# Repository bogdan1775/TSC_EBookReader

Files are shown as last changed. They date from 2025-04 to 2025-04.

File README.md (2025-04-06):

### Croitoru Constantin-Bogdan 334CA
# Proiect TSC

## Diagrama Bloc
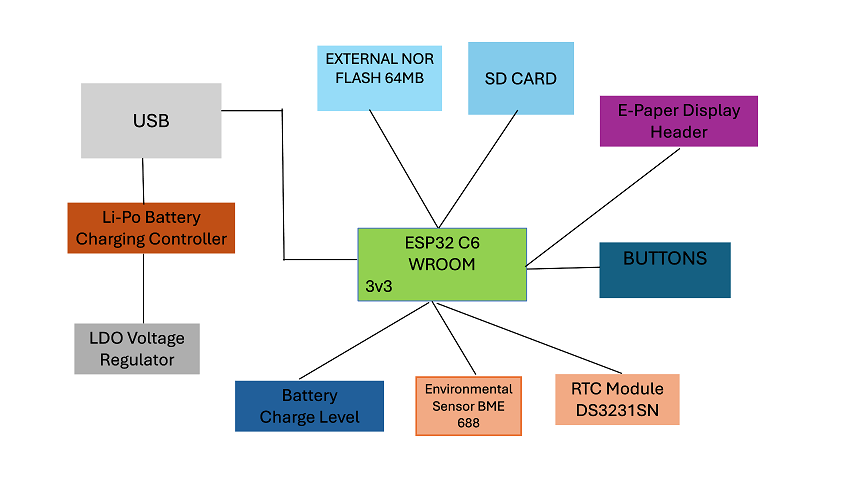
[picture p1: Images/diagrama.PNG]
Diagrama


## Bill Of Materials
| Nume | Link componenta | Link Datasheet |
|---|---|---|
|	BOOT_BUTTON	|	https://www.snapeda.com/parts/EVQP7L01P/Panasonic/view-part/?welcome=home&ref=search&t=evqp7l01p	|	https://industry.panasonic.com/global/en/downloads?tab=catalog&small_g_cd=203&part_no=EVQPUJ02K	|
|	C1	|	https://componentsearchengine.com/part-view/CC0402MRX5R5BB106/YAGEO	|	https://componentsearchengine.com/Datasheets/2/CC0402MRX5R5BB106.pdf	|
|	C1_BAT	|	https://componentsearchengine.com/part-view/CC0402MRX5R5BB106/YAGEO	|	https://componentsearchengine.com/Datasheets/2/CC0402MRX5R5BB106.pdf	|
|	C1_BAT1	|	https://www.snapeda.com/parts/CC0402DRNPO9BN5R1/Yageo/view-part/?ref=dk&t=LTSPICE_CC0402&con_ref=None	|	https://s3.amazonaws.com/snapeda/datasheet/CC0402DRNPO9BN5R1_Yageo.pdf	|
|	C2_BAT1	|	https://www.snapeda.com/parts/CC0402DRNPO9BN5R1/Yageo/view-part/?ref=dk&t=LTSPICE_CC0402&con_ref=None	|	https://s3.amazonaws.com/snapeda/datasheet/CC0402DRNPO9BN5R1_Yageo.pdf	|
|	C1_BAT2	| https://www.snapeda.com/parts/CC0402DRNPO9BN5R1/Yageo/view-part/?ref=dk&t=LTSPICE_CC0402&con_ref=None	|	https://s3.amazonaws.com/snapeda/datasheet/CC0402DRNPO9BN5R1_Yageo.pdf	|
|	C2	|	https://componentsearchengine.com/part-view/CC0402MRX5R5BB106/YAGEO	|	https://componentsearchengine.com/Datasheets/2/CC0402MRX5R5BB106.pdf	|
|	C2_BAT	|	https://componentsearchengine.com/part-view/CC0402MRX5R5BB106/YAGEO	|	https://componentsearchengine.com/Datasheets/2/CC0402MRX5R5BB106.pdf	|
|	C3	|	https://componentsearchengine.com/part-view/T491B107M006AT/KEMET	|	https://s3.amazonaws.com/snapeda/datasheet/TAJB475K025RNJ_AVX.pdf	|
|	C4	|	https://componentsearchengine.com/part-view/CC0402MRX5R5BB106/YAGEO	|	https://componentsearchengine.com/Datasheets/2/CC0402MRX5R5BB106.pdf	|
|	C4_USB	|	https://componentsearchengine.com/part-view/CC0402MRX5R5BB106/YAGEO	|	https://componentsearchengine.com/Datasheets/2/CC0402MRX5R5BB106.pdf	|
|	C5	|	https://componentsearchengine.com/part-view/CC0402MRX5R5BB106/YAGEO	|	https://componentsearchengine.com/Datasheets/2/CC0402MRX5R5BB106.pdf	|
|	C5_USB	|	https://componentsearchengine.com/part-view/CC0402MRX5R5BB106/YAGEO	|	https://componentsearchengine.com/Datasheets/2/CC0402MRX5R5BB106.pdf	|
|	C6	|	https://componentsearchengine.com/part-view/CC0402MRX5R5BB106/YAGEO	|	https://componentsearchengine.com/Datasheets/2/CC0402MRX5R5BB106.pdf	|
|	C7	|	https://componentsearchengine.com/part-view/CC0402MRX5R5BB106/YAGEO	|	https://componentsearchengine.com/Datasheets/2/CC0402MRX5R5BB106.pdf	|
|	C8	|	https://componentsearchengine.com/part-view/CC0402MRX5R5BB106/YAGEO	|	https://componentsearchengine.com/Datasheets/2/CC0402MRX5R5BB106.pdf	|
|	C9	|	https://www.snapeda.com/parts/CC0402DRNPO9BN5R1/Yageo/view-part/?ref=dk&t=LTSPICE_CC0402&con_ref=None	|	https://s3.amazonaws.com/snapeda/datasheet/CC0402DRNPO9BN5R1_Yageo.pdf	|
|	C10	|	https://componentsearchengine.com/part-view/CC0402MRX5R5BB106/YAGEO	|	https://componentsearchengine.com/Datasheets/2/CC0402MRX5R5BB106.pdf	|
|	C10_SUPERCAP	|	https://www.snapeda.com/parts/CPH3225A/Seiko+Instruments/view-part/?ref=eda	|	https://www.snapeda.com/parts/CPH3225A/Seiko%20Instruments/datasheet/	|
|	CHANGE_BUTTON	|	https://www.snapeda.com/parts/EVQP7L01P/Panasonic/view-part/?welcome=home&ref=search&t=evqp7l01p	|	https://industry.panasonic.com/global/en/downloads?tab=catalog&small_g_cd=203&part_no=EVQPUJ02K	|
|	CHG_LED	|	https://www.snapeda.com/parts/KP-1608SURCK/Kingbright/view-part/?ref=search&t=LED%200603	|	https://www.snapeda.com/parts/KP-1608SURCK/Kingbright/datasheet/	|
|	C_DELAY	|	https://componentsearchengine.com/part-view/CC0402MRX5R5BB106/YAGEO	|	https://componentsearchengine.com/Datasheets/2/CC0402MRX5R5BB106.pdf	|
|	D1	|	https://www.snapeda.com/parts/USBLC6-2SC6Y/STMicroelectronics/view-part/?ref=snap	|	https://www.snapeda.com/parts/USBLC6-2SC6Y/STMicroelectronics/datasheet/	|
|	D2	|	https://ro.mouser.com/ProductDetail/KYOCERA-AVX/SD0805S020S1R0?qs=jCA%252BPfw4LHbpkAoSnwrdjw%3D%3D	|	http://datasheets.avx.com/schottky.pdf	|
|	D3	|	https://www.snapeda.com/parts/MBR0530/Onsemi/view-part/?ref=eda	|	https://www.snapeda.com/parts/MBR0530/ON%20Semiconductor/datasheet/	|
|	D4	|	https://www.snapeda.com/parts/MBR0530/Onsemi/view-part/?ref=eda	|	https://www.snapeda.com/parts/MBR0530/ON%20Semiconductor/datasheet/	|
|	D5	|	https://www.snapeda.com/parts/MBR0530/Onsemi/view-part/?ref=eda	|	https://www.snapeda.com/parts/MBR0530/ON%20Semiconductor/datasheet/	|
|	D6	|	https://www.snapeda.com/parts/PGB1010603MR/Littelfuse/view-part/?ref=eda	|	https://www.snapeda.com/parts/PGB1010603MR/Littelfuse%20Inc./datasheet/	|
|	D7	|	https://ro.mouser.com/ProductDetail/KYOCERA-AVX/SD0805S020S1R0?qs=jCA%252BPfw4LHbpkAoSnwrdjw%3D%3D	|	http://datasheets.avx.com/schottky.pdf	|
|	D8	|	https://www.snapeda.com/parts/PGB1010603MR/Littelfuse/view-part/?ref=eda	|	https://www.snapeda.com/parts/PGB1010603MR/Littelfuse%20Inc./datasheet/	|
|	D9	|	https://www.snapeda.com/parts/PGB1010603MR/Littelfuse/view-part/?ref=eda	|	https://www.snapeda.com/parts/PGB1010603MR/Littelfuse%20Inc./datasheet/	|
|	D10	|	https://www.snapeda.com/parts/PGB1010603MR/Littelfuse/view-part/?ref=eda	|	https://www.snapeda.com/parts/PGB1010603MR/Littelfuse%20Inc./datasheet/	|
|	D11	|	https://www.snapeda.com/parts/PGB1010603MR/Littelfuse/view-part/?ref=eda	|	https://www.snapeda.com/parts/PGB1010603MR/Littelfuse%20Inc./datasheet/	|
|	D12	|	https://www.snapeda.com/parts/PGB1010603MR/Littelfuse/view-part/?ref=eda	|	https://www.snapeda.com/parts/PGB1010603MR/Littelfuse%20Inc./datasheet/	|
|	EPD_C1	|	https://componentsearchengine.com/part-view/CC0402MRX5R5BB106/YAGEO	|	https://componentsearchengine.com/Datasheets/2/CC0402MRX5R5BB106.pdf	|
|	EPD_C2	|	https://componentsearchengine.com/part-view/CC0402MRX5R5BB106/YAGEO	|	https://componentsearchengine.com/Datasheets/2/CC0402MRX5R5BB106.pdf	|
|	EPD_C5	|	https://componentsearchengine.com/part-view/CC0402MRX5R5BB106/YAGEO	|	https://componentsearchengine.com/Datasheets/2/CC0402MRX5R5BB106.pdf	|
|	EPD_C6	|	https://componentsearchengine.com/part-view/CC0402MRX5R5BB106/YAGEO	|	https://componentsearchengine.com/Datasheets/2/CC0402MRX5R5BB106.pdf	|
|	EPD_C7	|	https://componentsearchengine.com/part-view/CC0402MRX5R5BB106/YAGEO	|	https://componentsearchengine.com/Datasheets/2/CC0402MRX5R5BB106.pdf	|
|	EPD_C8	|	https://componentsearchengine.com/part-view/CC0402MRX5R5BB106/YAGEO	|	https://componentsearchengine.com/Datasheets/2/CC0402MRX5R5BB106.pdf	|
|	EPD_C9	|	https://componentsearchengine.com/part-view/CC0402MRX5R5BB106/YAGEO	|	https://componentsearchengine.com/Datasheets/2/CC0402MRX5R5BB106.pdf	|
|	EPD_C10	|	https://componentsearchengine.com/part-view/CC0402MRX5R5BB106/YAGEO	|	https://componentsearchengine.com/Datasheets/2/CC0402MRX5R5BB106.pdf	|
|	EPD_C11	|	https://componentsearchengine.com/part-view/CC0402MRX5R5BB106/YAGEO	|	https://componentsearchengine.com/Datasheets/2/CC0402MRX5R5BB106.pdf	|
|	EPD_C12	|	https://componentsearchengine.com/part-view/CC0402MRX5R5BB106/YAGEO	|	https://componentsearchengine.com/Datasheets/2/CC0402MRX5R5BB106.pdf	|
|	IC1	|	https://componentsearchengine.com/part-view/BD5229G-TR/ROHM%20Semiconductor	|	https://datasheet.datasheetarchive.com/originals/distributors/Datasheets_SAMA/f2b9741ef86007909f138d561a359946.pdf	|
|	IC4	|	https://componentsearchengine.com/part-view/XC6220A331MR-G/Torex	|	https://product.torexsemi.com/system/files/series/xc6220.pdf	|
|	J1	|	https://componentsearchengine.com/part-view/FH34SRJ-24S-0.5SH(99)/Hirose	|	https://www.hirose.com/en/product/document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	|
|	J2	|	https://componentsearchengine.com/part-view/USB4110-GF-A/GCT%20(GLOBAL%20CONNECTOR%20TECHNOLOGY)	|	https://gct.co/files/drawings/usb4110.pdf	|
|	J3	|	https://componentsearchengine.com/part-view/SM04B-SRSS-TB(LF)(SN)/JST%20(JAPAN%20SOLDERLESS%20TERMINALS)	| - |
|	J4	|	https://store.comet.srl.ro/Catalogue/Product/43497/	|	https://store.comet.srl.ro/Catalogue/Product/43497/	|
|	L1	|	https://ro.mouser.com/ProductDetail/Wurth-Elektronik/744043680?qs=PGXP4M47uW6VkZq%252BkzjrHA%3D%3D	|	https://www.we-online.com/components/products/datasheet/744043680.pdf	|
|	PFMF.050.1	|	https://ro.mouser.com/ProductDetail/EPCOS-TDK/B72520T0350K062?qs=dEfas%2FXlABIszF52uu7vrg%3D%3D	|	https://www.mouser.co.uk/ProductDetail/EPCOS-TDK/B72520T0350K062?qs=dEfas%2FXlABIszF52uu7vrg%3D%3D	|
|	Q1	|	https://componentsearchengine.com/part-view/DMG2305UX-7/Diodes%20Incorporated	|	https://www.diodes.com//assets/Datasheets/DMG2305UX.pdf	|
|	Q2	|	https://componentsearchengine.com/part-view/DMG2305UX-7/Diodes%20Incorporated	|	https://www.diodes.com//assets/Datasheets/DMG2305UX.pdf	|
|	Q3	|	https://componentsearchengine.com/part-view/SI1308EDL-T1-GE3/Vishay	|	https://componentsearchengine.com/Datasheets/1/SI1308EDL-T1-GE3.pdf	|
|	R1	|	https://componentsearchengine.com/part-view/R0402%201%25%20100%20K%20(RC0402FR-07100KL)/YAGEO	|	https://www.yageo.com/upload/media/product/products/datasheet/rchip/PYu-RC_Group_51_RoHS_L_12.pdf	|
|	R1-PINH	|	https://componentsearchengine.com/part-view/R0402%201%25%20100%20K%20(RC0402FR-07100KL)/YAGEO	|	https://www.yageo.com/upload/media/product/products/datasheet/rchip/PYu-RC_Group_51_RoHS_L_12.pdf	|
|	R1-PINH1	|	https://componentsearchengine.com/part-view/R0402%201%25%20100%20K%20(RC0402FR-07100KL)/YAGEO	|	https://www.yageo.com/upload/media/product/products/datasheet/rchip/PYu-RC_Group_51_RoHS_L_12.pdf	|
|	R1_BAT	|	https://componentsearchengine.com/part-view/R0402%201%25%20100%20K%20(RC0402FR-07100KL)/YAGEO	|	https://www.yageo.com/upload/media/product/products/datasheet/rchip/PYu-RC_Group_51_RoHS_L_12.pdf	|
|	R1_PWRUSB	|	https://componentsearchengine.com/part-view/R0402%201%25%20100%20K%20(RC0402FR-07100KL)/YAGEO	|	https://www.yageo.com/upload/media/product/products/datasheet/rchip/PYu-RC_Group_51_RoHS_L_12.pdf	|
|	R2	|	https://componentsearchengine.com/part-view/R0402%201%25%20100%20K%20(RC0402FR-07100KL)/YAGEO	|	https://www.yageo.com/upload/media/product/products/datasheet/rchip/PYu-RC_Group_51_RoHS_L_12.pdf	|
|	R2-PINH	|	https://componentsearchengine.com/part-view/R0402%201%25%20100%20K%20(RC0402FR-07100KL)/YAGEO	|	https://www.yageo.com/upload/media/product/products/datasheet/rchip/PYu-RC_Group_51_RoHS_L_12.pdf	|
|	R2-PINH1	|	https://componentsearchengine.com/part-view/R0402%201%25%20100%20K%20(RC0402FR-07100KL)/YAGEO	|	https://www.yageo.com/upload/media/product/products/datasheet/rchip/PYu-RC_Group_51_RoHS_L_12.pdf	|
|	R2-USB	|	https://componentsearchengine.com/part-view/R0402%201%25%20100%20K%20(RC0402FR-07100KL)/YAGEO	|	https://www.yageo.com/upload/media/product/products/datasheet/rchip/PYu-RC_Group_51_RoHS_L_12.pdf	|
|	R2-USB1	|	https://componentsearchengine.com/part-view/R0402%201%25%20100%20K%20(RC0402FR-07100KL)/YAGEO	|	https://www.yageo.com/upload/media/product/products/datasheet/rchip/PYu-RC_Group_51_RoHS_L_12.pdf	|
|	R2_BAT	|	https://componentsearchengine.com/part-view/R0402%201%25%20100%20K%20(RC0402FR-07100KL)/YAGEO	|	https://www.yageo.com/upload/media/product/products/datasheet/rchip/PYu-RC_Group_51_RoHS_L_12.pdf	|
|	R3	|	https://componentsearchengine.com/part-view/R0402%201%25%20100%20K%20(RC0402FR-07100KL)/YAGEO	|	https://www.yageo.com/upload/media/product/products/datasheet/rchip/PYu-RC_Group_51_RoHS_L_12.pdf	|
|	R4	|	https://componentsearchengine.com/part-view/R0402%201%25%20100%20K%20(RC0402FR-07100KL)/YAGEO	|	https://www.yageo.com/upload/media/product/products/datasheet/rchip/PYu-RC_Group_51_RoHS_L_12.pdf	|
|	R5	|	https://componentsearchengine.com/part-view/R0402%201%25%20100%20K%20(RC0402FR-07100KL)/YAGEO	|	https://www.yageo.com/upload/media/product/products/datasheet/rchip/PYu-RC_Group_51_RoHS_L_12.pdf	|
|	R6	|	https://componentsearchengine.com/part-view/R0402%201%25%20100%20K%20(RC0402FR-07100KL)/YAGEO	|	https://www.yageo.com/upload/media/product/products/datasheet/rchip/PYu-RC_Group_51_RoHS_L_12.pdf	|
|	R7	|	https://componentsearchengine.com/part-view/R0402%201%25%20100%20K%20(RC0402FR-07100KL)/YAGEO	|	https://www.yageo.com/upload/media/product/products/datasheet/rchip/PYu-RC_Group_51_RoHS_L_12.pdf	|
|	R8	|	https://componentsearchengine.com/part-view/R0402%201%25%20100%20K%20(RC0402FR-07100KL)/YAGEO	|	https://www.yageo.com/upload/media/product/products/datasheet/rchip/PYu-RC_Group_51_RoHS_L_12.pdf	|
|	R9	|	https://componentsearchengine.com/part-view/R0402%201%25%20100%20K%20(RC0402FR-07100KL)/YAGEO	|	https://www.yageo.com/upload/media/product/products/datasheet/rchip/PYu-RC_Group_51_RoHS_L_12.pdf	|
|	R10	|	https://componentsearchengine.com/part-view/R0402%201%25%20100%20K%20(RC0402FR-07100KL)/YAGEO	|	https://www.yageo.com/upload/media/product/products/datasheet/rchip/PYu-RC_Group_51_RoHS_L_12.pdf	|
|	RESET_BUTTON	|	https://www.snapeda.com/parts/EVQP7L01P/Panasonic/view-part/?welcome=home&ref=search&t=evqp7l01p	|	https://industry.panasonic.com/global/en/downloads?tab=catalog&small_g_cd=203&part_no=EVQPUJ02K	|
|	R_BOOT	|	https://componentsearchengine.com/part-view/R0402%201%25%20100%20K%20(RC0402FR-07100KL)/YAGEO	|	https://www.yageo.com/upload/media/product/products/datasheet/rchip/PYu-RC_Group_51_RoHS_L_12.pdf	|
|	R_CAPACITOR	|	https://componentsearchengine.com/part-view/R0402%201%25%20100%20K%20(RC0402FR-07100KL)/YAGEO	|	https://www.yageo.com/upload/media/product/products/datasheet/rchip/PYu-RC_Group_51_RoHS_L_12.pdf	|
|	R_CHANGE	|	https://componentsearchengine.com/part-view/R0402%201%25%20100%20K%20(RC0402FR-07100KL)/YAGEO	|	https://www.yageo.com/upload/media/product/products/datasheet/rchip/PYu-RC_Group_51_RoHS_L_12.pdf	|
|	R_CL1	|	https://componentsearchengine.com/part-view/R0402%201%25%20100%20K%20(RC0402FR-07100KL)/YAGEO	|	https://www.yageo.com/upload/media/product/products/datasheet/rchip/PYu-RC_Group_51_RoHS_L_12.pdf	|
|	R_RESET	|	https://componentsearchengine.com/part-view/R0402%201%25%20100%20K%20(RC0402FR-07100KL)/YAGEO	|	https://www.yageo.com/upload/media/product/products/datasheet/rchip/PYu-RC_Group_51_RoHS_L_12.pdf	|
|	SENSOR2	|	https://www.snapeda.com/parts/BME680/Bosch/view-part/?welcome=home	|	https://www.snapeda.com/parts/BME680/Bosch%20Sensortec/datasheet/	|
|	SJ1	|	https://grabcad.com/library/solder-jumpers-1	|	https://www.digikey.com/en/htmldatasheets/production/1809569/0/0/1/jumpers	|
|	U1	|	https://www.snapeda.com/parts/W25Q512JVEIQ/Winbond+Electronics/view-part/?ref=eda	|	https://www.snapeda.com/parts/W25Q512JVEIQ/Winbond%20Electronics/datasheet/	|
|	U2	|	https://www.snapeda.com/parts/ESP32-C6-WROOM-1-N8/Espressif+Systems/view-part/?ref=eda	|	https://www.snapeda.com/parts/ESP32-C6-WROOM-1-N8/Espressif%20Systems/datasheet/	|
|	U3	|	https://www.snapeda.com/parts/DS3231SN%23/Analog%20Devices/view-part/?ref=dk&t=DS3231SN%23&con_ref=None	|	https://www.snapeda.com/parts/DS3231SN%23/Analog%20Devices/datasheet/	|
|	U4	|	https://www.snapeda.com/parts/MAX17048G+T10/Analog+Devices/view-part/?ref=eda	|	https://www.snapeda.com/parts/MAX17048G+T10/Analog%20Devices/datasheet/	|
|	U5	|	https://ro.mouser.com/ProductDetail/Microchip-Technology/MCP73831T-2ACI-OT?qs=yUQqVecv4qvbBQBGbHx0Mw%3D%3D	|	https://ro.mouser.com/datasheet/2/268/MCP73831_Family_Data_Sheet_DS20001984H-3441711.pdf	|
|	TP1	|		|		|
|	TP2	|		|		|
|	TP3	|		|		|
|	TP4	|		|		|
|	TP5	|		|		|
|	TP6	|		|		|
|	TP7	|		|		|
|	TP8	|		|		|
|	TP9	|		|		|
|	TP10	|		|		|
|	TP11	|		|		|
|	TP12	|		|		|
|	TP13	|		|		|
|	TP14	|		|		|
|	TP15	|		|		|
|	TP16	|		|		|
|	TP17	|		|		|

## Descriere functionalitate
Dispozitivul este construit in jurul microcontrolerului ESP32-C6, care serveste ca unitate centrala de procesare si interactioneaza cu diverse componente esentiale pentru funcționarea sa.

Pentru a asigura o urmarire precisa a timpului, dispozitivul include un modul RTC DS3231SN, care comunica cu ESP32-C6 prin interfata I2C, garantand sincronizarea corecta a datelor si evenimentelor.

Senzorul de mediu BME680 este responsabil pentru colectarea informatiilor despre mediul înconjurator. Acesta transmite datele catre microcontroler prin I2C.

Dispozitivul beneficiaza si de un slot pentru card SD, utilizat pentru stocarea datelor colectate sau a altor informatii relevante. Acesta comunica cu ESP32-C6 prin interfata SPI, asigurand o stocare externa eficienta. De asemenea, exista o memorie Flash NOR externa de 64MB (W25Q512JVIQ) pentru stocarea firmware-ului si a altor date persistente.

Afisarea datelor si a altor informatii vizuale se realizeaza printr-un display E-Paper, care este conectat la ESP32-C6 prin pini GPIO dedicati.

In ceea ce priveste alimentarea, dispozitivul utilizeaza un conector USB-C (SAMACSYS_PARTS_USB4110-GF-A) cu protectie ESD, iar incarcarea bateriei Li-Po este gestionata de un controller de incarcare MCP73831. Un stabilizator de tensiune LDO (XC6220A331MR-G) asigura o alimentare stabila, iar nivelul de incarcare al bateriei este monitorizat cu ajutorul unui circuit MAX17048G+T.

Comunicarea intre componentele dispozitivului se face eficient datorita unui conector Qwiic (QWIIC_CONNECTORJS-1MM), care faciliteaza conectarea rapida a dispozitivelor I2C între ele.

In total, dispozitivul este un sistem complet si portabil, alimentat de o baterie Li-Po, cu conectivitate USB-C, care integreaza un microcontroler ESP32-C6, senzori pentru monitorizarea mediului, un RTC pentru urmarirea timpului si o solutie de stocare extinsa, toate interconectate prin interfetele I2C si SPI.

## Pini folositi
Modulul DS3231SN RTC si senzorul BME688: ambii folosesc pinii GPIO19 (SDA) si GPIO20 (SCL) pentru comunicarea I2C, un protocol serial pentru transferul de date.
Cardul SD: Comunica prin SPI, folosind pinii GPIO7 (MOSI), GPIO27 (MISO), GPIO4 (SS_SD) si GPIO6 (SCK) pentru transferul de date si sincronizare.
Display-ul E-Paper: Utilizeaza pini specifici pentru control: GPIO18 (EPD_3V3_C), GPIO11 (EPD_CS), GPIO5 (EPD_DC), GPIO21 (EPD_RST) si GPIO26 (EPD_BUSY).
Butoane: Pinii GPIO3 (RESET), GPIO15 (IO/BOOT) si GPIO23 (IO/CHANGE) sunt folositi pentru detectarea actiunilor utilizatorului, cum ar fi resetarea sau intrarea in modul de boot.

## Rezolvare Warnings
Am dat approve warning-urilor de tip Power de la schema electrica.
Am dat approve warningului "Pin A2 connected to VBUS".

## Rezolvare Errors
Am dat approve erorilor de la componenta J2.
Am rezolvat erorile de la Bobina L1 prin modificarea pad-urilor .
Am rezolvat erorile de la componenta U4.

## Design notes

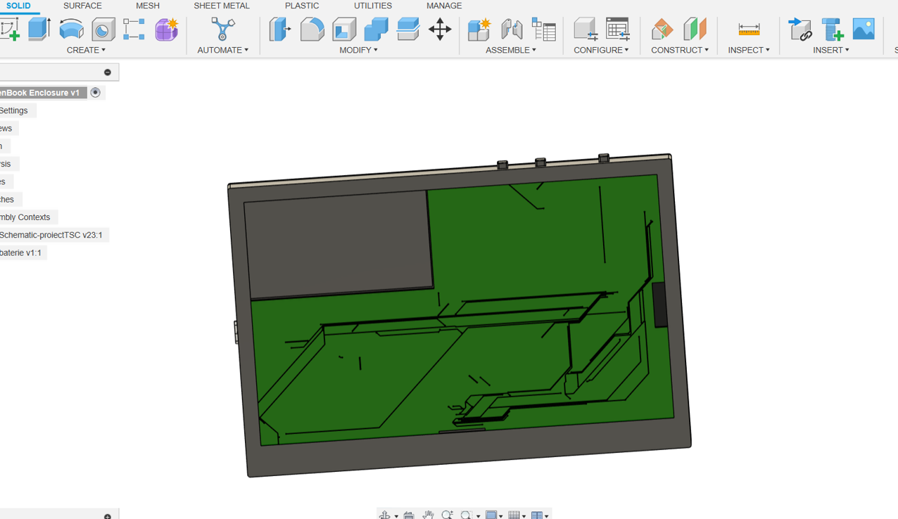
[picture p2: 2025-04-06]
Images/carcasa_fara_display.PNG

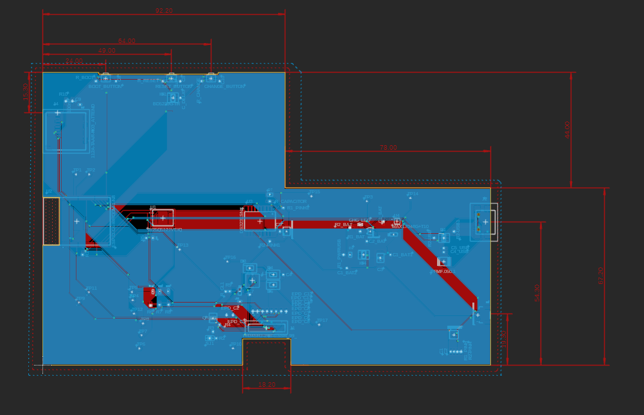
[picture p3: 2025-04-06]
Images/PCB-bottom.PNG

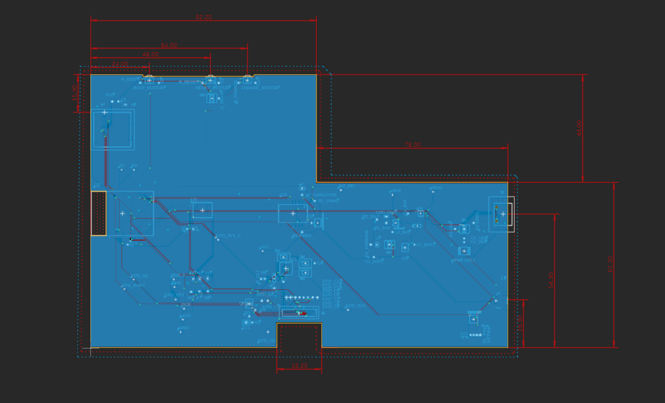
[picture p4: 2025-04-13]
Images/PCB-bottom-dupa_review.PNG

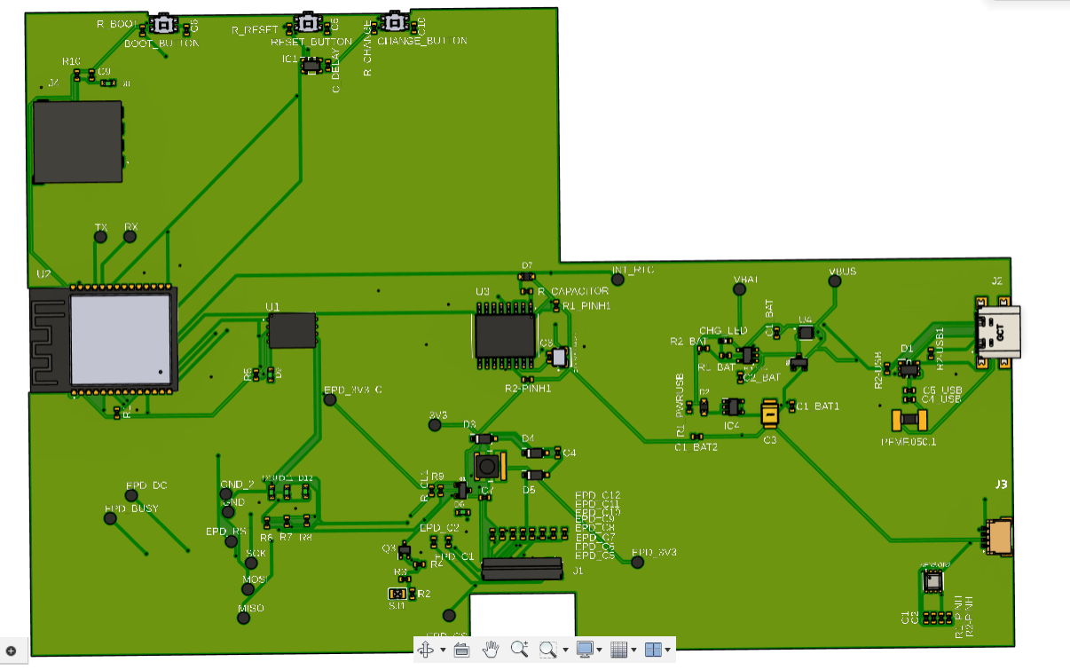
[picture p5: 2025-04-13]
Images/3d-dupa_review.PNG

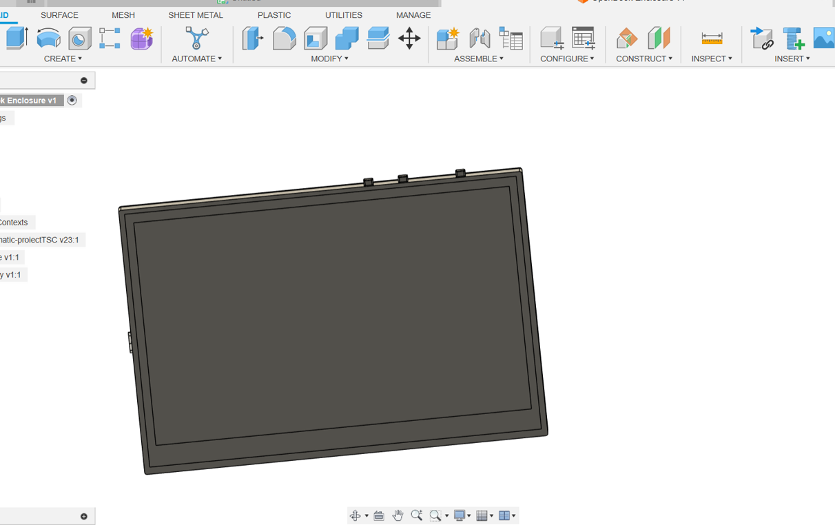
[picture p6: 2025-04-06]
Images/carcasa.PNG

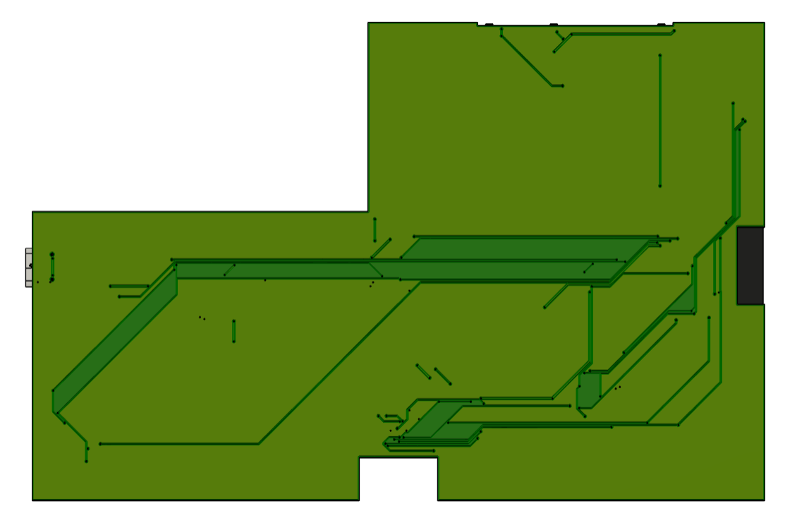
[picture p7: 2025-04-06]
Images/3d-bottom.PNG

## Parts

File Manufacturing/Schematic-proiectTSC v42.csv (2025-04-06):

Qty | Value | Device | Package | Parts | Description | ARROW_PART_NUMBER | ARROW_PRICE-STOCK | AVAILABILITY | CENTROID_NOT_SPECIFIED | CHECK_PRICES | COPYRIGHT | DATASHEET | DESCRIPTION | DIGIKEY_DESCRIPTION | DIGIKEY_PART_NUMBER | HEIGHT | LEAD_FREE | MANUFACTURER_NAME | MANUFACTURER_PART_NUMBER | MF | MFR_NAME | MOUSER_PART_NUMBER | MOUSER_PRICE-STOCK | MOUSER_TESTING_PART_NUMBER | MOUSER_TESTING_PRICE-STOCK | MP | MPN | PACKAGE | POPULARITY | PREFIX | PRICE | PROD_ID | PURCHASE-URL | ROHS | SNAPEDA_LINK | SPICEMODEL | SPICEPREFIX | TEMPERATURE_RANGE_HIGH | TEMPERATURE_RANGE_LOW | TP_SIGNAL_NAME | VALUE
1 |  | ADAFRUIT_LEDCHIP-LED0603 | ADAFRUIT_CHIP-LED0603 | CHG_LED | LED
1 |  | SJ | SJ | SJ1 | SMD solder JUMPER |  |  |  |  |  |  |  |  |  |  |  |  |  |  |  |  |  |  |  |  |  |  |  | 3
1 | 0.1uF/50V | ESP32_WROVER_EAGLE-LTSPICE_CC0402 | EAGLE-LTSPICE_C0402 | EPD_C5 | CAPACITOR, European symbol |  |  |  |  |  |  |  |  |  |  |  |  |  |  |  |  |  |  |  |  |  |  |  |  |  |  |  |  |  |  | NONE | C
1 | 0.47 | ESP32_WROVER_EAGLE-LTSPICE_RR0402 | ESP32_WROVER_EAGLE-LTSPICE_R0402 | R3 | RESISTOR, European symbol |  |  |  |  |  |  |  |  |  |  |  |  |  |  |  |  |  |  |  |  |  |  |  |  |  |  |  |  |  |  | NONE | R
1 | 100k | ESP32_WROVER_EAGLE-LTSPICE_RR0402 | ESP32_WROVER_EAGLE-LTSPICE_R0402 | R1_PWRUSB | RESISTOR, European symbol |  |  |  |  |  |  |  |  |  |  |  |  |  |  |  |  |  |  |  |  |  |  |  |  |  |  |  |  |  |  | NONE | R
1 | 100nF | EAGLE-LTSPICE_CC0402 | EAGLE-LTSPICE_C0402 | C4_USB | CAPACITOR, European symbol |  |  |  |  |  |  |  |  |  |  |  |  |  |  |  |  |  |  |  |  |  |  |  |  |  |  |  |  |  |  | NONE | C
7 | 100nF | ESP32_WROVER_EAGLE-LTSPICE_CC0402 | EAGLE-LTSPICE_C0402 | C1, C2, C6, C8, C9, C10, C_DELAY | CAPACITOR, European symbol |  |  |  |  |  |  |  |  |  |  |  |  |  |  |  |  |  |  |  |  |  |  |  |  |  |  |  |  |  |  | NONE | C
1 | 100uF TANT | RCL_CPOL-EUCT3528 | RCL_CT3528 | C3 | POLARIZED CAPACITOR, European symbol |  |  |  |  |  |  |  |  |  |  |  |  |  |  |  |  |  |  |  |  |  |  |  | 0 |  |  |  |  |  |  |  | C
6 | 10K | ESP32_WROVER_EAGLE-LTSPICE_RR0402 | ESP32_WROVER_EAGLE-LTSPICE_R0402 | R5, R6, R7, R8, R9, R10 | RESISTOR, European symbol |  |  |  |  |  |  |  |  |  |  |  |  |  |  |  |  |  |  |  |  |  |  |  |  |  |  |  |  |  |  | NONE | R
10 | 10k | ESP32_WROVER_EAGLE-LTSPICE_RR0402 | ESP32_WROVER_EAGLE-LTSPICE_R0402 | R1, R1_PINH, R1_PINH1, R2-PINH, R2-PINH1, R4, R_BOOT, R_CHANGE, R_CL1, R_RESET | RESISTOR, European symbol |  |  |  |  |  |  |  |  |  |  |  |  |  |  |  |  |  |  |  |  |  |  |  |  |  |  |  |  |  |  | NONE | R
1 | 10uF | ESP32_WROVER_EAGLE-LTSPICE_CC0402 | EAGLE-LTSPICE_C0402 | C7 | CAPACITOR, European symbol |  |  |  |  |  |  |  |  |  |  |  |  |  |  |  |  |  |  |  |  |  |  |  |  |  |  |  |  |  |  | NONE | C
1 | 112A-TAAR-R03_ATTEND | 112A-TAAR-R03_ATTEND | 112ATAARR03ATTEND | J4 | Micro SD Card Socket, Push-Push Type, Top Mount, SMT, H=1.83mm, 10u |  |  |  |  |  |  |  | Micro SD Card Socket | Push-Push Type | Top Mount | SMT | H=1.83mm | 10u |  |  | 1.9mm |  | ATTEND | 112A-TAAR-R03 ATTEND
1 | 15 | ESP32_WROVER_EAGLE-LTSPICE_RR0402 | ESP32_WROVER_EAGLE-LTSPICE_R0402 | R_CAPACITOR | RESISTOR, European symbol |  |  |  |  |  |  |  |  |  |  |  |  |  |  |  |  |  |  |  |  |  |  |  |  |  |  |  |  |  |  | NONE | R
1 | 1uF | ESP32_WROVER_EAGLE-LTSPICE_CC0402 | EAGLE-LTSPICE_C0402 | C5 | CAPACITOR, European symbol |  |  |  |  |  |  |  |  |  |  |  |  |  |  |  |  |  |  |  |  |  |  |  |  |  |  |  |  |  |  | NONE | C
9 | 1uF/50V | ESP32_WROVER_EAGLE-LTSPICE_CC0402 | EAGLE-LTSPICE_C0402 | EPD_C1, EPD_C2, EPD_C6, EPD_C7, EPD_C8, EPD_C9, EPD_C10, EPD_C11, EPD_C12 | CAPACITOR, European symbol |  |  |  |  |  |  |  |  |  |  |  |  |  |  |  |  |  |  |  |  |  |  |  |  |  |  |  |  |  |  | NONE | C
1 | 2.2 | ESP32_WROVER_EAGLE-LTSPICE_RR0402 | ESP32_WROVER_EAGLE-LTSPICE_R0402 | R2 | RESISTOR, European symbol |  |  |  |  |  |  |  |  |  |  |  |  |  |  |  |  |  |  |  |  |  |  |  |  |  |  |  |  |  |  | NONE | R
1 | 200 | ESP32_WROVER_EAGLE-LTSPICE_RR0402 | ESP32_WROVER_EAGLE-LTSPICE_R0402 | R1_BAT | RESISTOR, European symbol |  |  |  |  |  |  |  |  |  |  |  |  |  |  |  |  |  |  |  |  |  |  |  |  |  |  |  |  |  |  | NONE | R
2 | 20V/4.2A/52mO/1.4W | ESP32_WROVER_SPARKFUN-DISCRETESEMI_MOSFET_PCH-DMG2305UX-7 | ESP32_WROVER_SPARKFUN-DISCRETESEMI_SOT23-3 | Q1, Q2 | P-channel MOSFETs |  |  |  |  |  |  |  |  |  |  |  |  |  |  |  |  |  |  |  |  |  |  |  |  |  |  | TRAN-14388 |  |  |  |  |  |  |  |  | 20V/4.2A/52mO/1.4W
1 | 2k | ESP32_WROVER_EAGLE-LTSPICE_RR0402 | ESP32_WROVER_EAGLE-LTSPICE_R0402 | R2_BAT | RESISTOR, European symbol |  |  |  |  |  |  |  |  |  |  |  |  |  |  |  |  |  |  |  |  |  |  |  |  |  |  |  |  |  |  | NONE | R
1 | 4.7uF | EAGLE-LTSPICE_CC0402 | EAGLE-LTSPICE_C0402 | C5_USB | CAPACITOR, European symbol |  |  |  |  |  |  |  |  |  |  |  |  |  |  |  |  |  |  |  |  |  |  |  |  |  |  |  |  |  |  | NONE | C
4 | 4.7uF | ESP32_WROVER_EAGLE-LTSPICE_CC0402 | EAGLE-LTSPICE_C0402 | C1_BAT, C1_BAT1, C1_BAT2, C2_BAT | CAPACITOR, European symbol |  |  |  |  |  |  |  |  |  |  |  |  |  |  |  |  |  |  |  |  |  |  |  |  |  |  |  |  |  |  | NONE | C
1 | 4.7uF/25V | ESP32_WROVER_EAGLE-LTSPICE_CC0402 | EAGLE-LTSPICE_C0402 | C4 | CAPACITOR, European symbol |  |  |  |  |  |  |  |  |  |  |  |  |  |  |  |  |  |  |  |  |  |  |  |  |  |  |  |  |  |  | NONE | C
1 | 5K1 | ESP32_WROVER_EAGLE-LTSPICE_RR0402 | ESP32_WROVER_EAGLE-LTSPICE_R0402 | R2-USB1 | RESISTOR, European symbol |  |  |  |  |  |  |  |  |  |  |  |  |  |  |  |  |  |  |  |  |  |  |  |  |  |  |  |  |  |  | NONE | R
1 | 5k1 | ESP32_WROVER_EAGLE-LTSPICE_RR0402 | ESP32_WROVER_EAGLE-LTSPICE_R0402 | R2-USB | RESISTOR, European symbol |  |  |  |  |  |  |  |  |  |  |  |  |  |  |  |  |  |  |  |  |  |  |  |  |  |  |  |  |  |  | NONE | R
1 | 68uH | 744043680IND_4828-WE-TPC_WRE | IND_4828-WE-TPC_WRE | L1 |  |  |  |  |  |  | Copyright (C) 2024 Ultra Librarian. All rights reserved. |  |  |  |  |  |  |  | 744043680 |  | Wurth Electronics
1 | BD5229G-TR | BD5229G-TR | SOT95P280X125-5N | IC1 | Voltage Detector with Adjustable Delay Time: CMOS processes are utilized to develop high precision, low current consumption CMOS reset ICs that allow arbitrary setting of the delay time. The extensive lineup includes both Nch Open Drain and CMOS output types in a wide range of detection voltages (from 2.3V to 6.0V, in 0.1V steps), enabling selection of the ideal solution based on customer requirements. In addition, the entire series is of course both lead-free and RoHS-compliant. |  |  |  |  |  |  |  | Voltage Detector with Adjustable Delay Time: CMOS processes are utilized to develop high precision | low current consumption CMOS reset ICs that allow arbitrary setting of the delay time. The extensive lineup includes both Nch Open Drain and CMOS output types in a wide range of detection voltages (from 2.3V to 6.0V | in 0.1V steps) | enabling selection of the ideal solution based on customer requirements. In addition | the entire series is of course both lead-free and RoHS-compliant. |  |  | 1.25mm |  | ROHM Semiconductor | BD5229G-TR |  |  | 755-BD5229G-TR | https://www.mouser.co.uk/ProductDetail/ROHM-Semiconductor/BD5229G-TR?qs=4kLU8WoGk0vvnhrrYwdszw%3D%3D
3 | BUTTON_CUSYOMV1 | BUTTON_CUSYOMV1 | MYBUTTON | BOOT_BUTTON, CHANGE_BUTTON, RESET_BUTTON
1 | CPH3225A | CPH3225A | CAPCP3225X100N | C10_SUPERCAP | Cap 0.011F 3.3V 1210 Flat Check availability |  |  | Not in stock |  | https://www.snapeda.com/parts/CPH3225A/Seiko+Instruments/view-part/?ref=eda |  |  | 11 mF (EDLC) Supercapacitor 3.3 V 1210 (3225 Metric) - - |  |  |  |  |  |  | Seiko Instruments |  |  |  |  |  | CPH3225A |  | 1210 Seiko |  |  | None |  | https://www.snapeda.com/api/url_track_click_mouser/?unipart_id=562593&manufacturer=Seiko Instruments&part_name=CPH3225A&search_term=None |  | https://www.snapeda.com/parts/CPH3225A/Seiko+Instruments/view-part/?ref=snap
1 | DS3231SN# | DS3231SN# | SOIC127P1032X265-16N | U3 | Real Time Clock Serial 16-Pin SOIC W T/R Check availability |  |  | In Stock |  | https://www.snapeda.com/parts/DS3231SN%23/Analog+Devices/view-part/?ref=eda |  |  | Extremely Accurate I²C-Integrated RTC/TCXO/Crystal |  |  |  |  |  |  | Analog Devices |  |  |  |  |  | DS3231SN# |  | SOIC-16 Maxim |  |  | None |  | https://www.snapeda.com/api/url_track_click_mouser/?unipart_id=99048&manufacturer=Analog Devices&part_name=DS3231SN#&search_term=None |  | https://www.snapeda.com/parts/DS3231SN%23/Analog+Devices/view-part/?ref=snap
1 | ESP32-C6-WROOM-1-N8 | ESP32-C6-WROOM-1-N8 | XCVR_ESP32-C6-WROOM-1-N8 | U2 | Check availability |  |  | In Stock |  | https://www.snapeda.com/parts/ESP32-C6-WROOM-1-N8/Espressif+Systems/view-part/?ref=eda |  |  | Multiprotocol Modules ESP32-C6 module | Wi-Fi 6 in 2.4 GHz band | Bluetooth 5 | Zigbee 3.0 and Thread. ESP34-WROOM Compatible - ENGINEERING SAMPLE |  |  |  |  |  |  | Espressif Systems |  |  |  |  |  | ESP32-C6-WROOM-1-N8 |  | None |  |  | None |  |  |  | https://www.snapeda.com/parts/ESP32-C6-WROOM-1-N8/Espressif+Systems/view-part/?ref=snap
1 | ESP32C6_VARISTORCN1812 | ESP32C6_VARISTORCN1812 | ESP32C6_VARISTOR_CT/CN1812 | PFMF.050.1 | VARISTOR |  |  |  |  |  |  |  |  |  |  |  |  |  |  |  |  |  |  |  |  |  |  |  | 0
2 | ESP32_WROVER_AVX---SD0805S020S1R0_AVX_SD0805S020S1R0_0_0AVX_SD0805S020S1R0_0_0 | ESP32_WROVER_AVX---SD0805S020S1R0_AVX_SD0805S020S1R0_0_0AVX_SD0805S020S1R0_0_0 | ESP32_WROVER_AVX---SD0805S020S1R0_AVX_SD0805S020S1R0_0 | D2, D7 | Schottky Barrier Rectifier Diode |  |  |  | No |  |  | http://datasheets.avx.com/schottky.pdf |  | DIODE SCHOTTKY 20V 1A 0805 | 478-7800-1-ND |  | yes |  |  | AVX |  | 581-SD0805S020S1R0 |  |  |  |  |  | 0805 (2012 metric) |  | D |  |  |  | yes |  |  |  | +125°C | -55°C
1 | ESP32_WROVER_BME680_BME680 | ESP32_WROVER_BME680_BME680 | ESP32_WROVER_BME680_PSON80P300X300X100-8N | SENSOR2 | Integrated Environmental Unit |  |  | Unavailable |  |  |  |  | Integrated Environmental Unit |  |  |  |  |  |  | Bosch Sensortec |  |  |  |  |  | BME680 |  | LGA-8 Bosch Tools |  |  | None
1 | ESP32_WROVER_SPARKFUN-IC-POWER_MCP73831 | ESP32_WROVER_SPARKFUN-IC-POWER_MCP73831 | ESP32_WROVER_SPARKFUN-IC-POWER_SOT23-5 | MCP73831 | MCP73831T Li-Ion, Li-Pol Controller |  |  |  |  |  |  |  |  |  |  |  |  |  |  |  |  |  |  |  |  |  |  |  |  |  |  | IC-09995
1 | FH34SRJ-24S-0.5SH_99_ | FH34SRJ-24S-0.5SH_99_ | FH34SRJ24S05SH99 | J1 | (0.50mm) Surface Mount, Right Angle |  |  |  |  |  |  |  | 24 Position FFC | FPC Connector Contacts | (0.50mm) Surface Mount | Right Angle |  |  | 1.1mm |  | Hirose | FH34SRJ-24S-0.5SH(99) |  |  | 798-FH34SRJ24S05SH99 | https://www.mouser.co.uk/ProductDetail/Hirose-Connector/FH34SRJ-24S-0.5SH99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
1 | MAX17048G+T10 | MAX17048G+T10 | SON50P200X200X80-9N | U4 | Check availability |  |  | In Stock |  | https://www.snapeda.com/parts/MAX17048G+T10/Analog+Devices/view-part/?ref=eda |  |  | 3µA 1-Cell/2-Cell Fuel Gauge with ModelGauge |  |  |  |  |  |  | Analog Devices |  |  |  |  |  | MAX17048G+T10 |  | TDFN-8 Maxim |  |  | None |  | https://www.snapeda.com/api/url_track_click_mouser/?unipart_id=329239&manufacturer=Analog Devices&part_name=MAX17048G+T10&search_term=None |  | https://www.snapeda.com/parts/MAX17048G+T10/Analog+Devices/view-part/?ref=snap
3 | MBR0530 | MBR0530 | SOD3716X135N | D3, D4, D5 | ON SEMICONDUCTOR - MBR0530 - DIODE, SCHOTTKY, 0.5A, 30V, SOD-123 |  |  | In Stock |  | https://www.snapeda.com/parts/MBR0530/Onsemi/view-part/?ref=eda |  |  | Diode Schottky 30 V 500mA Surface Mount SOD-123 |  |  |  |  |  |  | ON Semiconductor |  |  |  |  |  | MBR0530 |  | SOD-123-2 ON Semiconductor |  |  | None |  | https://www.snapeda.com/api/url_track_click_mouser/?unipart_id=179458&manufacturer=ON Semiconductor&part_name=MBR0530&search_term=None |  | https://www.snapeda.com/parts/MBR0530/Onsemi/view-part/?ref=snap
6 | PGB1010603MR | PGB1010603MR | DIOC1608X36N | D6, D8, D9, D10, D11, D12 | Check availability |  |  | In Stock |  | https://www.snapeda.com/parts/PGB1010603MR/Littelfuse/view-part/?ref=eda |  |  | 150V (Typ) Clamp - Ipp Tvs Diode Surface Mount 0603 (1608 Metric) |  |  |  |  |  |  | Littelfuse Inc. |  |  |  |  |  | PGB1010603MR |  | 0603 Littelfuse Inc. |  |  | None |  | https://www.snapeda.com/api/url_track_click_mouser/?unipart_id=5659453&manufacturer=Littelfuse Inc.&part_name=PGB1010603MR&search_term=None |  | https://www.snapeda.com/parts/PGB1010603MR/Littelfuse/view-part/?ref=snap
1 | QWIIC_RIGHT_ANGLE | QWIIC_CONNECTORJS-1MM | JST04_1MM_RA | J3 | SparkFun I2C Standard Qwiic Connector |  |  |  |  |  |  |  |  |  |  |  |  |  |  |  |  |  |  |  |  |  |  |  |  |  |  | CONN-13694 |  |  |  |  |  |  |  |  | QWIIC_RIGHT_ANGLE
1 | SAMACSYS_PARTS_USB4110-GF-A | SAMACSYS_PARTS_USB4110-GF-A | SAMACSYS_PARTS_USB4110GFA | J2 | CONN USB 2.0 TYPE-C R/A SMT |  |  |  |  |  |  |  | CONN USB 2.0 TYPE-C R/A SMT |  |  | 3.26mm |  | GCT (GLOBAL CONNECTOR TECHNOLOGY) | USB4110-GF-A |  |  | 640-USB4110-GF-A | https://www.mouser.co.uk/ProductDetail/GCT/USB4110-GF-A?qs=KUoIvG%2F9IlYiZvIXQjyJeA%3D%3D
1 | SI1308EDL-T1-GE3 | SI1308EDL-T1-GE3 | SOT65P210X110-3N | Q3 | MOSFET N-Ch 30V 1.5A TrenchFET SC70 Vishay Si1308EDL-T1-GE3 N-channel MOSFET Transistor, 1.5 A, 30 V, 3-Pin SC-70 |  |  | In Stock |  | https://www.snapeda.com/parts/SI1308EDL-T1-GE3/Vishay+Siliconix/view-part/?ref=eda |  |  | Si1308EDL-T1-GE3 N-channel MOSFET Transistor | 1.5 A | 30 V | 3-Pin SC-70 | Siliconix / Vishay SI1308EDL-T1-GE3 |  |  |  |  |  |  | Vishay Siliconix |  |  |  |  |  | SI1308EDL-T1-GE3 |  | SOT-323 Vishay Semiconductor |  |  | None |  | https://www.snapeda.com/api/url_track_click_mouser/?unipart_id=274603&manufacturer=Vishay Siliconix&part_name=SI1308EDL-T1-GE3&search_term=None |  | https://www.snapeda.com/parts/SI1308EDL-T1-GE3/Vishay+Siliconix/view-part/?ref=snap
17 | TPTP20R | TPTP20R | TP20R | TP1, TP2, TP3, TP4, TP5, TP6, TP7, TP8, TP9, TP10, TP11, TP12, TP13, TP14, TP15, TP16, TP17 | Test pad |  |  |  |  |  |  |  |  |  |  |  |  |  |  |  |  |  |  |  |  |  |  |  | 2
1 | USBLC6-2SC6Y | USBLC6-2SC6Y | SOT95P280X145-6N | D1 | Low Cap. ESD Protection Auto SOT-23-6 STMicroelectronics USBLC6-2SC6Y, Dual Uni-Directional TVS Diode Array, 6-Pin SOT-23 |  |  | In Stock |  | https://www.snapeda.com/parts/USBLC6-2SC6Y/STMicroelectronics/view-part/?ref=eda |  |  | 17V Clamp 5A (8/20µs) Ipp Tvs Diode Surface Mount SOT-23-6 |  |  |  |  |  |  | STMicroelectronics |  |  |  |  |  | USBLC6-2SC6Y |  | SOT-23-6 STMicroelectronics |  |  | None |  |  |  | https://www.snapeda.com/parts/USBLC6-2SC6Y/STMicroelectronics/view-part/?ref=snap
1 | W25Q512JVEIQ | W25Q512JVEIQ | SON127P600X800X80-9N | U1 | Check availability |  |  | In Stock |  | https://www.snapeda.com/parts/W25Q512JVEIQ/Winbond+Electronics/view-part/?ref=eda |  |  | FLASH - NOR Memory IC 512Mb (64M x 8) SPI - Quad I/O 133 MHz 8-WSON (8x6) |  |  |  |  |  |  | Winbond Electronics |  |  |  |  |  | W25Q512JVEIQ |  | Package |  |  | None |  |  |  | https://www.snapeda.com/parts/W25Q512JVEIQ/Winbond+Electronics/view-part/?ref=snap
1 | XC6220A331MR-G | XC6220A331MR-G | SOT95P280X120-5N | IC4 | LDO Voltage Regulators |  |  |  |  |  |  |  | LDO Voltage Regulators |  |  | 1.2mm |  | Torex | XC6220A331MR-G |  |  | 865-XC6220A331MR-G | https://www.mouser.co.uk/ProductDetail/Torex-Semiconductor/XC6220A331MR-G?qs=AsjdqWjXhJ8ZSWznL1J0gg%3D%3D

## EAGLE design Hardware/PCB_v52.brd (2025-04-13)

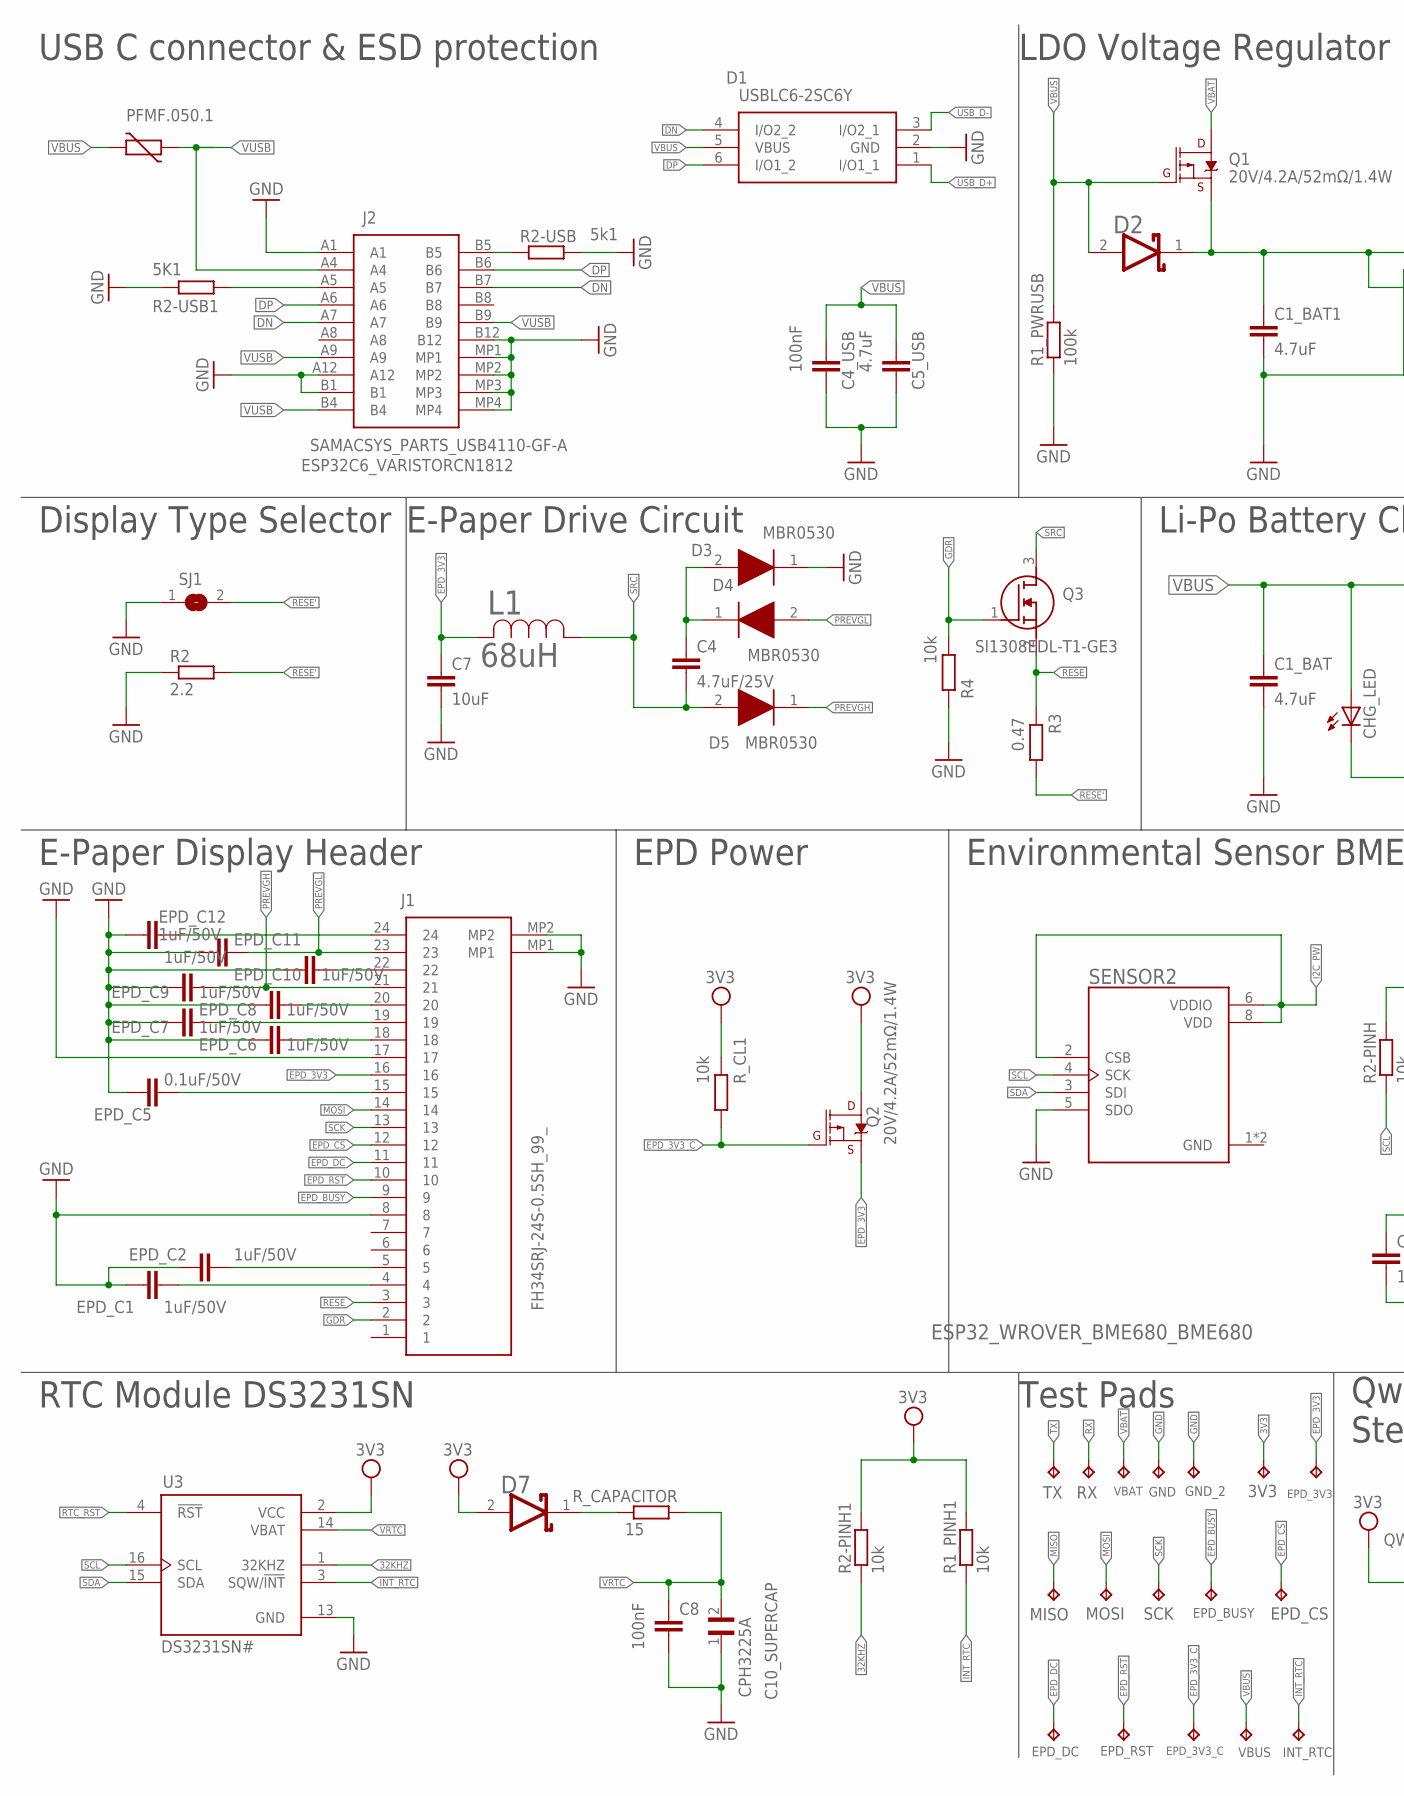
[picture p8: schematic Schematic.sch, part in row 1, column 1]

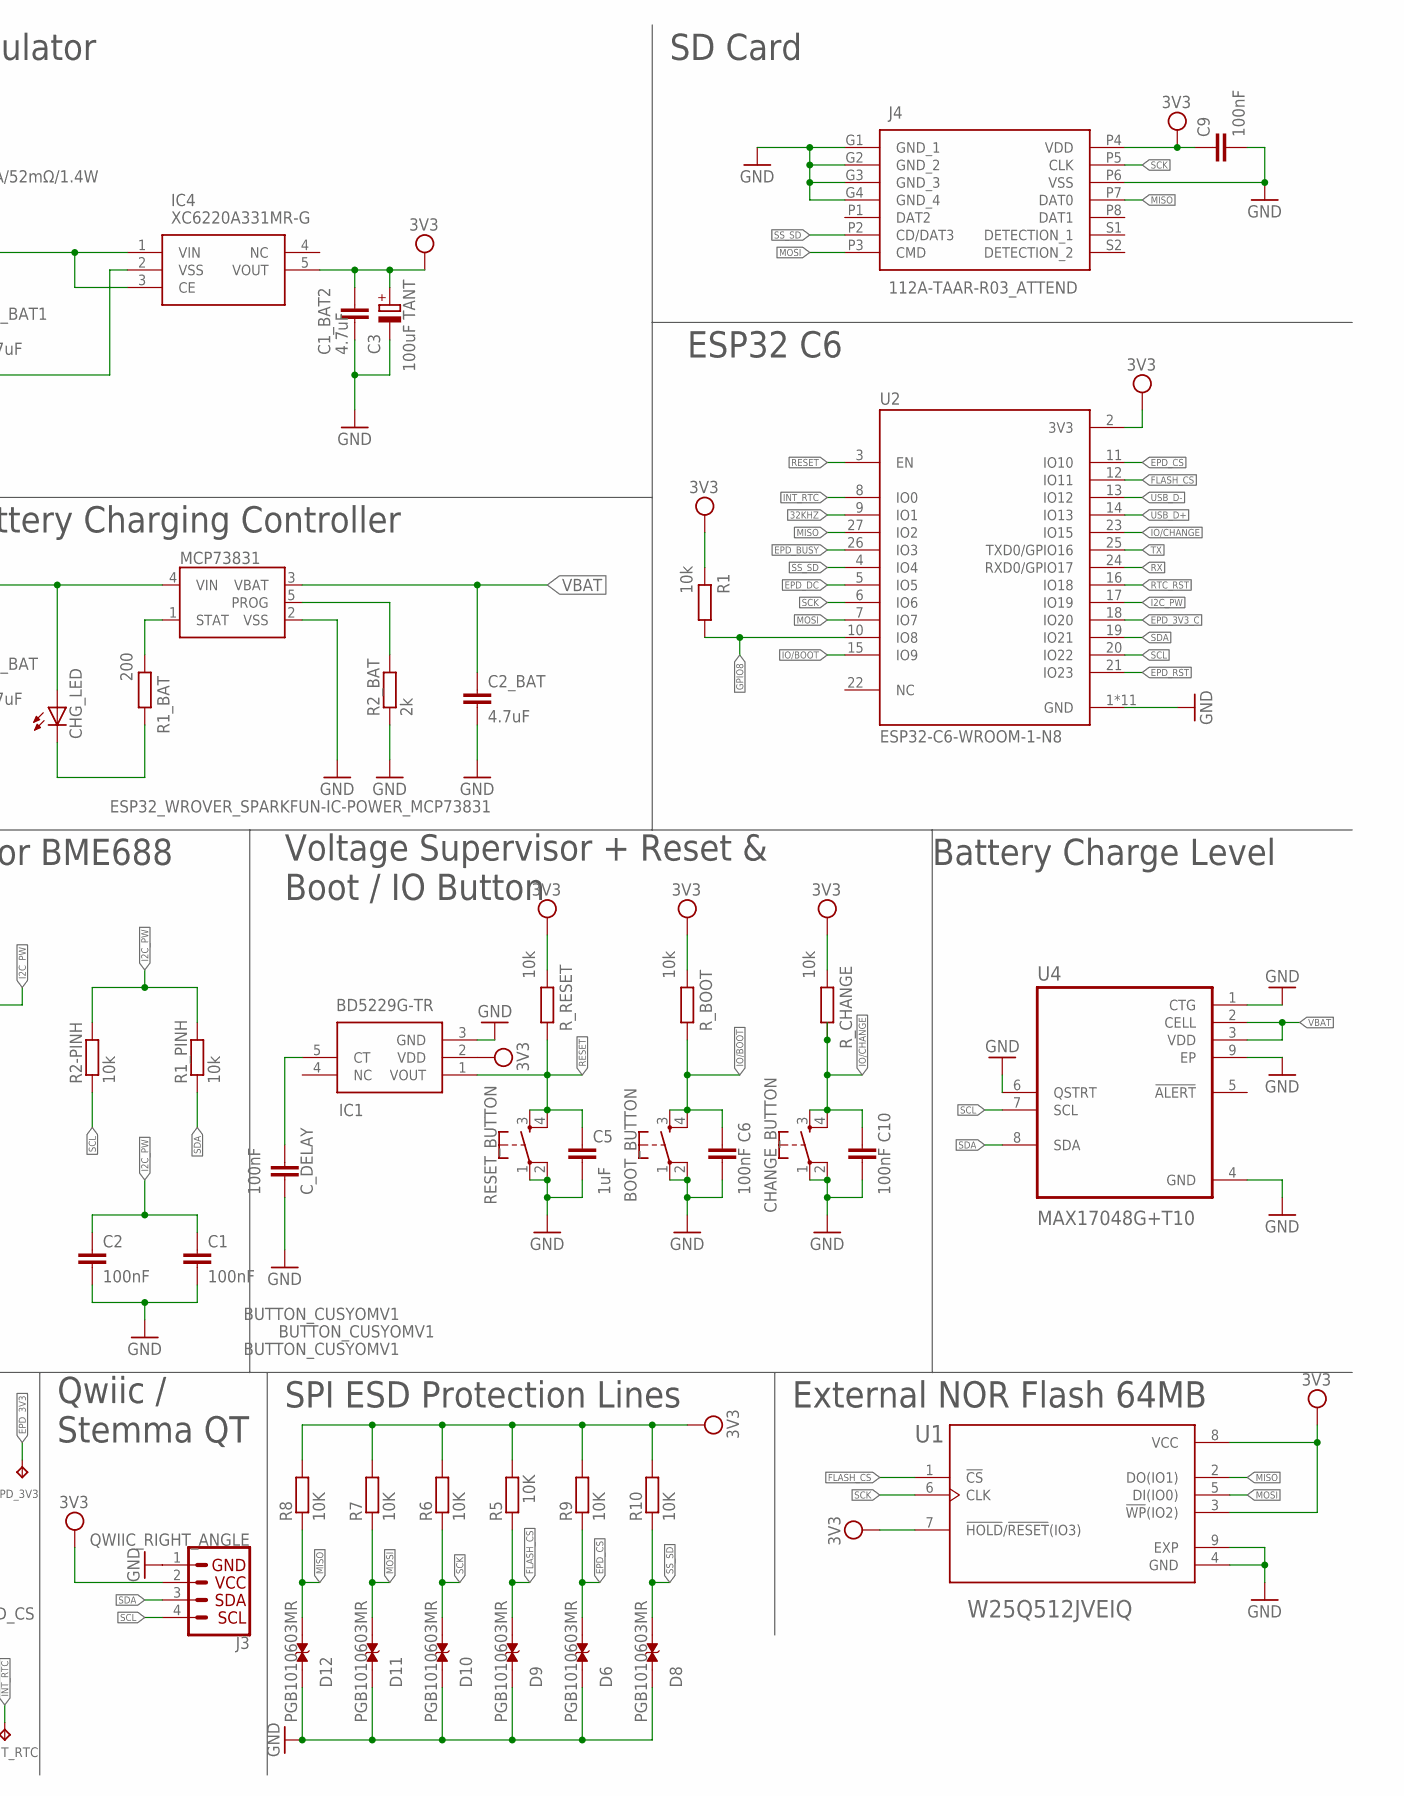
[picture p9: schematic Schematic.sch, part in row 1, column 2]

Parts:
3V3: TPTP20R; TP20R
BOOT_BUTTON: BUTTON_CUSYOMV1; MYBUTTON
C1, C2, C4_USB, C6, C8, C9, C10: 100nF; EAGLE-LTSPICE_C0402
C1_BAT, C1_BAT1, C1_BAT2, C2_BAT, C5_USB: 4.7uF; EAGLE-LTSPICE_C0402
C3: 100uF TANT; RCL_CT3528
C4: 4.7uF/25V; EAGLE-LTSPICE_C0402
C5: 1uF; EAGLE-LTSPICE_C0402
C7: 10uF; EAGLE-LTSPICE_C0402
C10_SUPERCAP: CPH3225A; CAPCP3225X100N
CHANGE_BUTTON: BUTTON_CUSYOMV1; MYBUTTON
CHG_LED: ADAFRUIT_LEDCHIP-LED0603; ADAFRUIT_CHIP-LED0603
C_DELAY: 100nF; EAGLE-LTSPICE_C0402
D1: USBLC6-2SC6Y; SOT95P280X145-6N
D2, D7: ESP32_WROVER_AVX---SD0805S020S1R0_AVX_SD0805S020S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; ESP32_WROVER_AVX---SD0805S020S1R0_AVX_SD0805S020S1R0_0
D3, D4, D5: MBR0530; SOD3716X135N
D6, D8, D9, D10, D11, D12: PGB1010603MR; DIOC1608X36N
EPD_3V3, EPD_3V3_C: TPTP20R; TP20R
EPD_BUSY: TPTP20R; TP20R
EPD_C1, EPD_C2, EPD_C6, EPD_C7, EPD_C8, EPD_C9, EPD_C10, EPD_C11, EPD_C12: 1uF/50V; EAGLE-LTSPICE_C0402
EPD_C5: 0.1uF/50V; EAGLE-LTSPICE_C0402
EPD_CS: TPTP20R; TP20R
EPD_DC: TPTP20R; TP20R
EPD_RST: TPTP20R; TP20R
GND: TPTP20R; TP20R
GND_2: TPTP20R; TP20R
IC1: BD5229G-TR; SOT95P280X125-5N
IC4: XC6220A331MR-G; SOT95P280X120-5N
INT_RTC: TPTP20R; TP20R
J1: FH34SRJ-24S-0.5SH_99_; FH34SRJ24S05SH99
J2: SAMACSYS_PARTS_USB4110-GF-A; SAMACSYS_PARTS_USB4110GFA
J3: QWIIC_RIGHT_ANGLE; JST04_1MM_RA
J4: 112A-TAAR-R03_ATTEND; 112ATAARR03ATTEND
L1: 68uH; IND_4828-WE-TPC_WRE
MCP73831: ESP32_WROVER_SPARKFUN-IC-POWER_MCP73831; ESP32_WROVER_SPARKFUN-IC-POWER_SOT23-5
MISO: TPTP20R; TP20R
MOSI: TPTP20R; TP20R
PFMF.050.1: ESP32C6_VARISTORCN1812; ESP32C6_VARISTOR_CT/CN1812
Q1, Q2: 20V/4.2A/52mΩ/1.4W; ESP32_WROVER_SPARKFUN-DISCRETESEMI_SOT23-3
Q3: SI1308EDL-T1-GE3; SOT65P210X110-3N
R1, R1_PINH, R1_PINH1, R2-PINH, R2-PINH1, R4: 10k; ESP32_WROVER_EAGLE-LTSPICE_R0402
R1_BAT: 200; ESP32_WROVER_EAGLE-LTSPICE_R0402
R1_PWRUSB: 100k; ESP32_WROVER_EAGLE-LTSPICE_R0402
R2: 2.2; ESP32_WROVER_EAGLE-LTSPICE_R0402
R2-USB: 5k1; ESP32_WROVER_EAGLE-LTSPICE_R0402
R2-USB1: 5K1; ESP32_WROVER_EAGLE-LTSPICE_R0402
R2_BAT: 2k; ESP32_WROVER_EAGLE-LTSPICE_R0402
R3: 0.47; ESP32_WROVER_EAGLE-LTSPICE_R0402
R5, R6, R7, R8, R9, R10: 10K; ESP32_WROVER_EAGLE-LTSPICE_R0402
RESET_BUTTON: BUTTON_CUSYOMV1; MYBUTTON
RX: TPTP20R; TP20R
R_BOOT: 10k; ESP32_WROVER_EAGLE-LTSPICE_R0402
R_CAPACITOR: 15; ESP32_WROVER_EAGLE-LTSPICE_R0402
R_CHANGE: 10k; ESP32_WROVER_EAGLE-LTSPICE_R0402
R_CL1: 10k; ESP32_WROVER_EAGLE-LTSPICE_R0402
R_RESET: 10k; ESP32_WROVER_EAGLE-LTSPICE_R0402
SCK: TPTP20R; TP20R
SENSOR2: ESP32_WROVER_BME680_BME680; ESP32_WROVER_BME680_PSON80P300X300X100-8N
SJ1: SJ
TX: TPTP20R; TP20R
U1: W25Q512JVEIQ; SON127P600X800X80-9N
U2: ESP32-C6-WROOM-1-N8; XCVR_ESP32-C6-WROOM-1-N8
U3: DS3231SN#; SOIC127P1032X265-16N
U4: MAX17048G+T10; SON50P200X200X80-9N
VBAT: TPTP20R; TP20R
VBUS: TPTP20R; TP20R

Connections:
3V3: 3V3.TP, C1_BAT2.1, C3.+, C9.1, D7.2 (ANODE), IC1.2 (VDD), IC4.5 (VOUT), J3.2, J4.P4 (VDD), Q2.3 (D), R1.2, R1_PINH1.2, R2-PINH1.2, R5.2, R6.2, R7.2, R8.2, R9.2, R10.2, R_BOOT.2, R_CHANGE.2, R_CL1.2, R_RESET.2, U1.3 (!WP!(IO2)), U1.7 (!HOLD!/!RESET!(IO3)), U1.8 (VCC), U2.2 (3V3), U3.2 (VCC)
32KHZ: R2-PINH1.1, U2.9 (IO1), U3.1 (32KHZ)
DN: D1.4 (I/O2_2), J2.A7, J2.B7
DP: D1.6 (I/O1_2), J2.A6, J2.B6
EPD_3V3: C7.1, EPD_3V3.TP, J1.16, L1.2, Q2.2 (S)
EPD_3V3_C: EPD_3V3_C.TP, Q2.1 (G), R_CL1.1, U2.18 (IO20)
EPD_BUSY: EPD_BUSY.TP, J1.9, U2.26 (IO3)
EPD_CS: D6.2, EPD_CS.TP, J1.12, R9.1, U2.11 (IO10)
EPD_DC: EPD_DC.TP, J1.11, U2.5 (IO5)
EPD_RST: EPD_RST.TP, J1.10, U2.21 (IO23)
FLASH_CS: D9.2, R5.1, U1.1 (!CS), U2.12 (IO11)
GDR: J1.2, Q3.1 (G), R4.2
GND: BOOT_BUTTON.1, BOOT_BUTTON.2, C1.2, C1_BAT.2, C1_BAT1.2, C1_BAT2.2, C2.2, C2_BAT.2, C3.-, C4_USB.2, C5.2, C5_USB.2, C6.2, C7.2, C8.2, C9.2, C10.2, C10_SUPERCAP.1, CHANGE_BUTTON.1, CHANGE_BUTTON.2, C_DELAY.2, D1.2 (GND), D3.1 (K), D6.1, D8.1, D9.1, D10.1, D11.1, D12.1, EPD_C1.2, EPD_C2.2, EPD_C5.2, EPD_C6.2, EPD_C7.2, EPD_C8.2, EPD_C9.2, EPD_C10.2, EPD_C11.2, EPD_C12.1, GND.TP, GND_2.TP, IC1.3 (GND), IC4.2 (VSS), J1.8, J1.17, J1.MP1, J1.MP2, J2.A1, J2.A12, J2.B1, J2.B12, J2.MP1, J2.MP2, J2.MP3, J2.MP4, J3.1, J4.G1 (GND_1), J4.G2 (GND_2), J4.G3 (GND_3), J4.G4 (GND_4), J4.P6 (VSS), MCP73831.2 (VSS), R1_PWRUSB.1, R2.1, R2-USB.2, R2-USB1.1, R2_BAT.1, R4.1, RESET_BUTTON.1, RESET_BUTTON.2, SENSOR2.1 (GND), SENSOR2.5 (SDO), SENSOR2.7 (GND), SJ1.1, U1.4 (GND), U1.9 (EXP), U2.1 (GND), U2.28 (GND), U2.29_1 (GND), U2.29_2 (GND), U2.29_3 (GND), U2.29_4 (GND), U2.29_5 (GND), U2.29_6 (GND), U2.29_7 (GND), U2.29_8 (GND), U2.29_9 (GND), U3.13 (GND), U4.1 (CTG), U4.4 (GND), U4.6 (QSTRT), U4.9 (EP)
GPIO8: R1.1, U2.10 (IO8)
I2C_PW: C1.1, C2.1, R1_PINH.2, R2-PINH.2, SENSOR2.2 (CSB), SENSOR2.6 (VDDIO), SENSOR2.8 (VDD), U2.17 (IO19)
INT_RTC: INT_RTC.TP, R1_PINH1.1, U2.8 (IO0), U3.3 (SQW/!INT)
IO/BOOT: BOOT_BUTTON.3, BOOT_BUTTON.4, C6.1, R_BOOT.1, U2.15 (IO9)
IO/CHANGE: C10.1, CHANGE_BUTTON.3, CHANGE_BUTTON.4, R_CHANGE.1, U2.23 (IO15)
MISO: D12.2, J4.P7 (DAT0), MISO.TP, R8.1, U1.2 (DO(IO1)), U2.27 (IO2)
MOSI: D11.2, J1.14, J4.P3 (CMD), MOSI.TP, R7.1, U1.5 (DI(IO0)), U2.7 (IO7)
unnamed: C_DELAY.1, IC1.5 (CT)
unnamed: J2.B5, R2-USB.1
unnamed: J2.A5, R2-USB1.2
unnamed: D7.1 (CATHODE), R_CAPACITOR.1
unnamed: C1_BAT1.1, D2.1 (CATHODE), IC4.1 (VIN), IC4.3 (CE), Q1.2 (S)
unnamed: MCP73831.1 (STAT), R1_BAT.2
unnamed: CHG_LED.C, R1_BAT.1
unnamed: C4.1, D3.2 (A), D4.1 (K)
unnamed: MCP73831.5 (PROG), R2_BAT.2
unnamed: EPD_C12.2, J1.24
unnamed: EPD_C10.1, J1.22
unnamed: EPD_C8.1, J1.20
unnamed: EPD_C7.1, J1.19
unnamed: EPD_C6.1, J1.18
unnamed: EPD_C5.1, J1.15
unnamed: EPD_C1.1, J1.4
unnamed: EPD_C2.1, J1.5
PREVGH: D5.1 (K), EPD_C9.1, J1.21
PREVGL: D4.2 (A), EPD_C11.1, J1.23
RESE: J1.3, Q3.2 (S), R3.2
RESE': R2.2, R3.1, SJ1.2
RESET: C5.1, IC1.1 (VOUT), RESET_BUTTON.3, RESET_BUTTON.4, R_RESET.1, U2.3 (EN)
RTC_RST: U2.16 (IO18), U3.4 (!RST)
RX: RX.TP, U2.24 (RXD0/GPIO17)
SCK: D10.2, J1.13, J4.P5 (CLK), R6.1, SCK.TP, U1.6 (CLK), U2.6 (IO6)
SCL: J3.4, R2-PINH.1, SENSOR2.4 (SCK), U2.20 (IO22), U3.16 (SCL), U4.7 (SCL)
SDA: J3.3, R1_PINH.1, SENSOR2.3 (SDI), U2.19 (IO21), U3.15 (SDA), U4.8 (SDA)
SRC: C4.2, D5.2 (A), L1.1, Q3.3 (D)
SS_SD: D8.2, J4.P2 (CD/DAT3), R10.1, U2.4 (IO4)
TX: TX.TP, U2.25 (TXD0/GPIO16)
USB_D+: D1.1 (I/O1_1), U2.14 (IO13)
USB_D-: D1.3 (I/O2_1), U2.13 (IO12)
VBAT: C2_BAT.1, MCP73831.3 (VBAT), Q1.3 (D), U4.2 (CELL), U4.3 (VDD), VBAT.TP
VBUS: C1_BAT.1, C4_USB.1, C5_USB.1, CHG_LED.A, D1.5 (VBUS), D2.2 (ANODE), J2.A8, MCP73831.4 (VIN), PFMF.050.1.2, Q1.1 (G), R1_PWRUSB.2, VBUS.TP
VRTC: C8.1, C10_SUPERCAP.2, R_CAPACITOR.2, U3.14 (VBAT)
VUSB: J2.A4, J2.A9, J2.B4, J2.B9, PFMF.050.1.1

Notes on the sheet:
USB C connector & ESD protection
LDO Voltage Regulator
SD Card
Display Type Selector
E-Paper Drive Circuit
Li-Po Battery Charging Controller
ESP32 C6
E-Paper Display Header
EPD Power
Environmental Sensor BME688
Battery Charge Level
Voltage Supervisor + Reset & Boot / IO Button
RTC Module DS3231SN
Test Pads
Qwiic / Stemma QT
SPI ESD Protection Lines
External NOR Flash 64MB

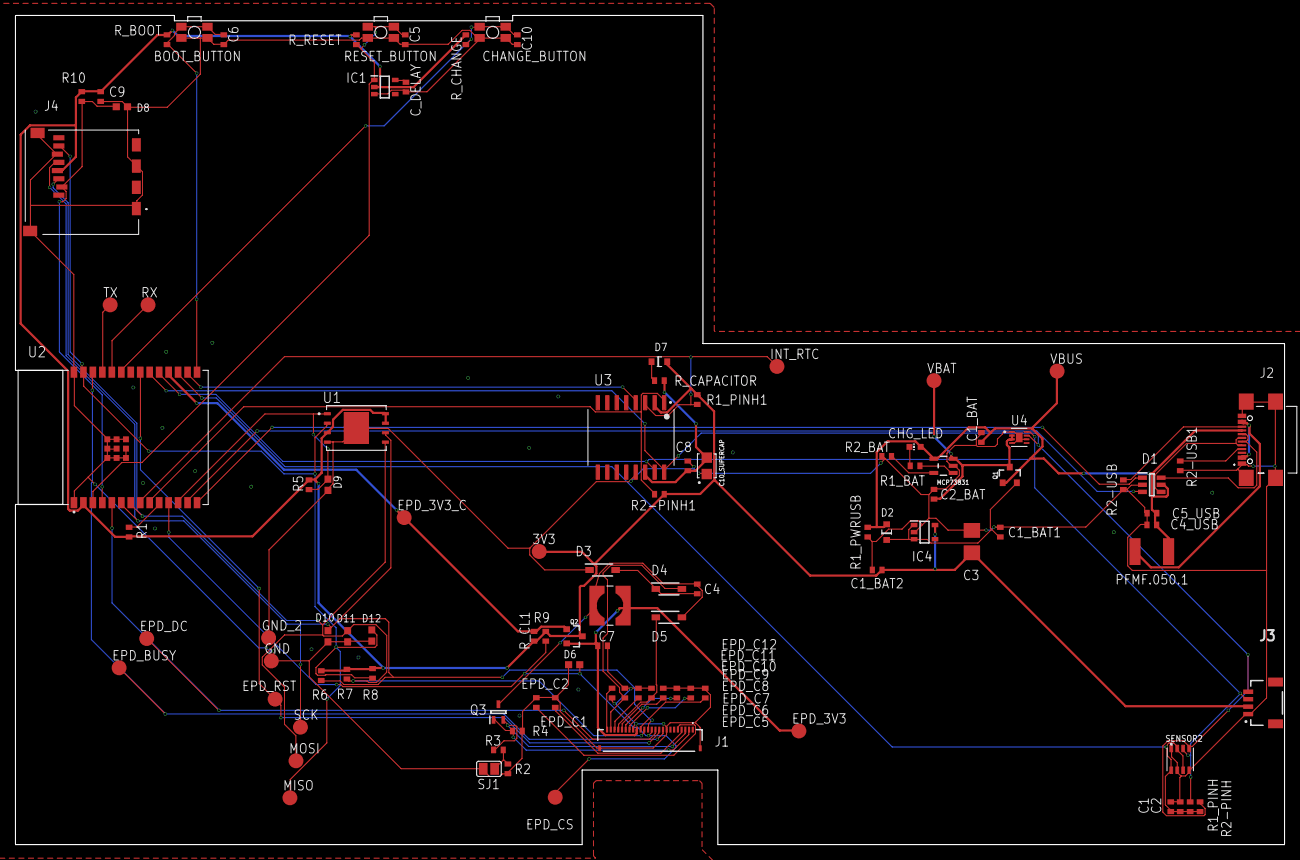
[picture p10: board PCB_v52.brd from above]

Board: 2 copper layers, 170.2 x 111.2 mm, 103 parts (0 on the bottom side), 56 nets.

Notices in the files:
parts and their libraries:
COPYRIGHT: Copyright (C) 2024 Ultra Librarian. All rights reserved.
